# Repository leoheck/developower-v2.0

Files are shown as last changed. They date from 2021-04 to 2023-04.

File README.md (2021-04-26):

## Developower-v2.0

This project is an effort to recreate Developower-v2.0 board on Kicad.

This is the Developower-v2.0 board used on those Chinese 3018 CNC's.

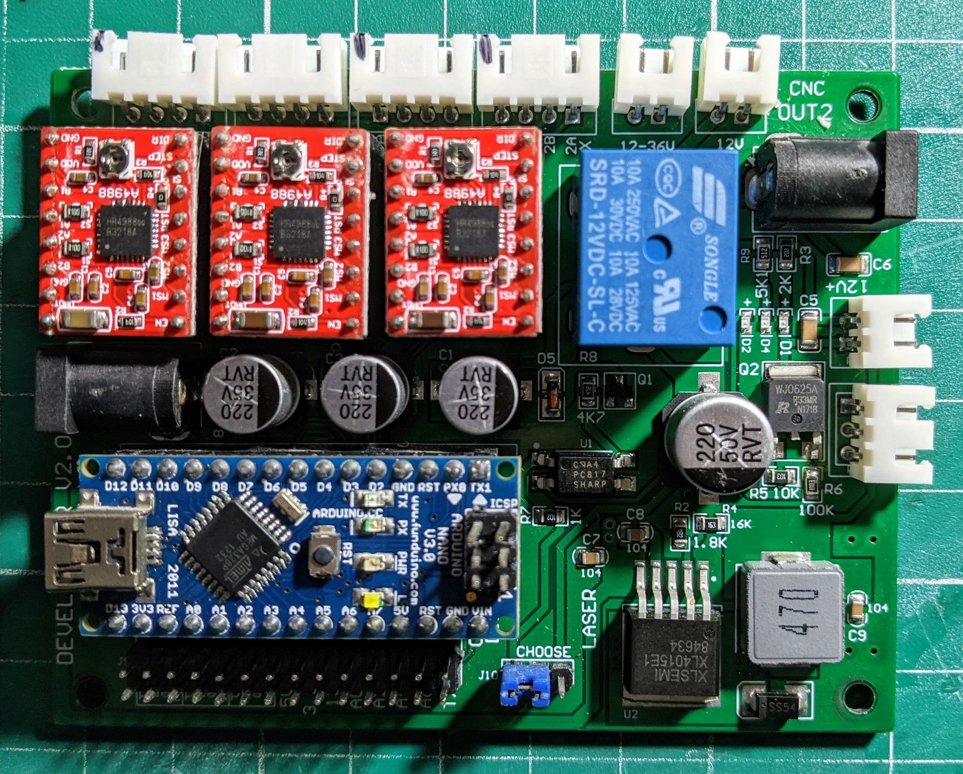
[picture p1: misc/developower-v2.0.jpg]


This is the current version of the layout, but it is still a work in progress.

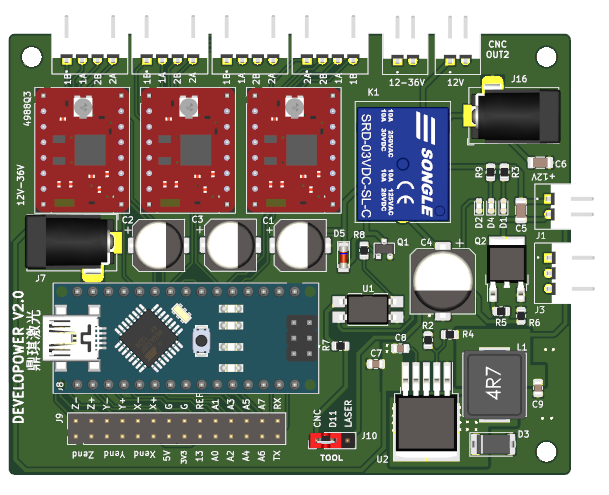
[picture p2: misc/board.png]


A simple cover for the board can be found here too.

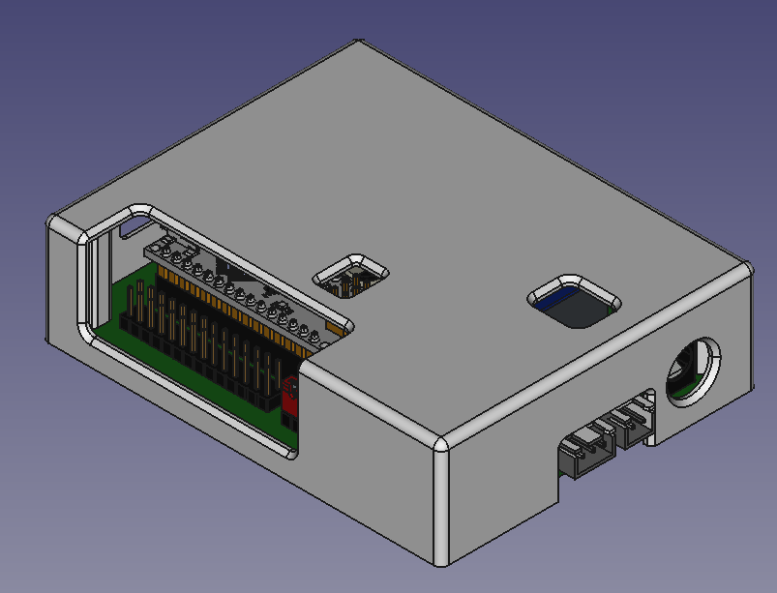
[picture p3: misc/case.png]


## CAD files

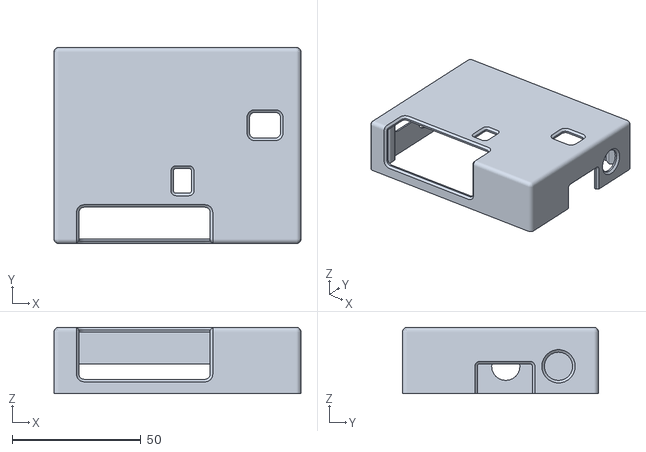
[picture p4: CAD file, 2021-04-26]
case/cover.stl
96.0 x 76.2 x 25.8

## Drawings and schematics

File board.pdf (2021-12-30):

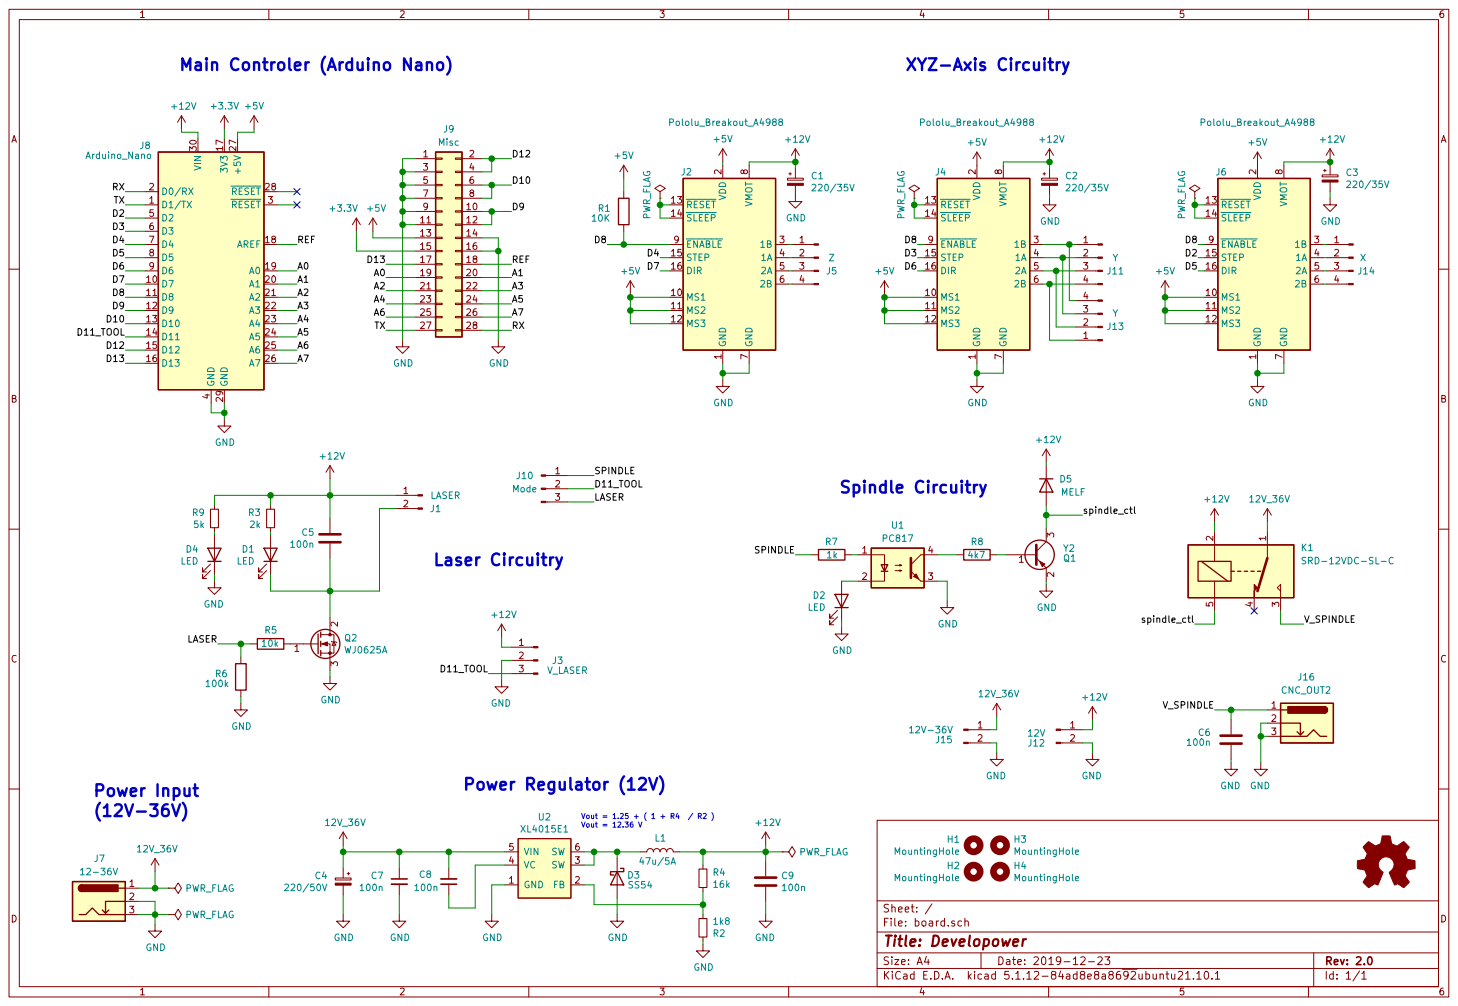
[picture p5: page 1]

9 | 10
11 | 12

1 MS1 10 MS2 11 MS3 12 RESET 13 SLEEP 14 STEP 15 DIR 16 VDD

2 3 Q2WJ0625A GND
Id: 1/1 Title: Developower File: board.sch Sheet: / R5

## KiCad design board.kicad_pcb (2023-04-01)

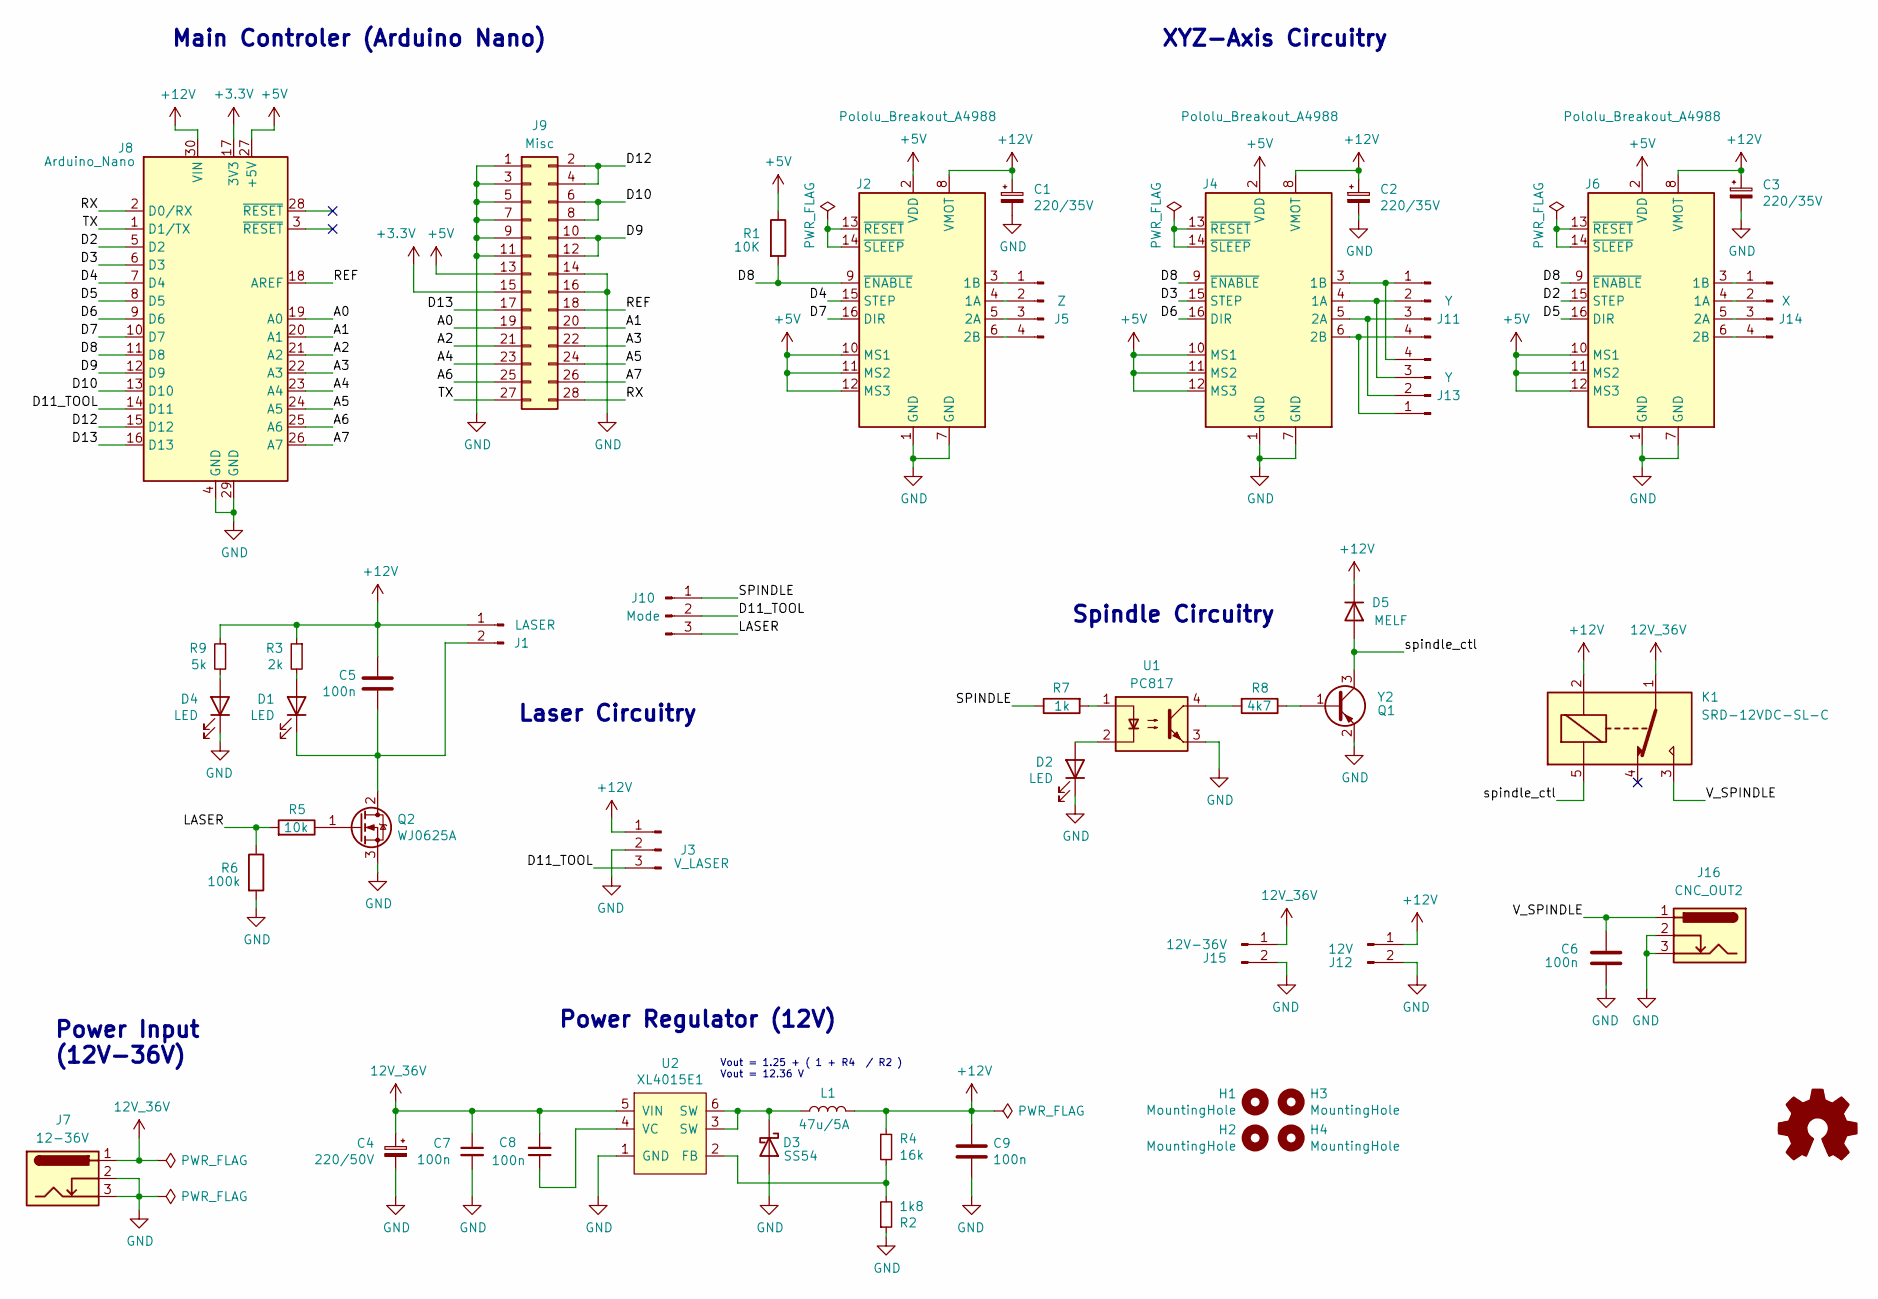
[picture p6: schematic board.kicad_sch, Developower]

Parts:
C1, C2, C3: 220/35V; CP_Elec_8x10
C4: 220/50V; CP_Elec_10x10.5
C5, C6: 100n; C_1206_3216Metric
C7, C8, C9: 100n; C_0805_2012Metric
D1, D2, D4: LED; LED_0603_1608Metric
D3: SS54; D_2512_6332Metric
D5: MELF; D_MiniMELF
H1, H2, H3, H4: MountingHole; MountingHole_3.2mm_M3
J1: LASER; JST_S2B-XH-A(LF)(SN)
J2, J4, J6: Pololu_Breakout_A4988; Pololu_Breakout-16_15.2x20.3mm
J3: V_LASER; JST_S3B-XH-A(LF)(SN)
J5: Z; JST_S4B-XH-A(LF)(SN)
J7: 12-36V; BarrelJack_Horizontal
J8: Arduino_Nano
J9: Misc; PinHeader_2x14_P2.54mm_Vertical
J10: Mode; PinHeader_1x03_P2.54mm_Vertical
J11, J13: Y; JST_S4B-XH-A(LF)(SN)
J12: 12V; JST_S2B-XH-A(LF)(SN)
J14: X; JST_S4B-XH-A(LF)(SN)
J15: 12V-36V; JST_S2B-XH-A(LF)(SN)
J16: CNC_OUT2; BarrelJack_Horizontal
K1: SRD-12VDC-SL-C; Relay_SPDT_SANYOU_SRD_Series_Form_C
L1: 47u/5A; L_Vishay_IHLP-4040
Q1: Y2; SC-59
Q2: WJ0625A; TO-252-2
R1: 10K; R_0805_2012Metric
R2: 1k8; R_0805_2012Metric
R3: 2k; R_0805_2012Metric
R4: 16k; R_0805_2012Metric
R5: 10k; R_0805_2012Metric
R6: 100k; R_0805_2012Metric
R7: 1k; R_0805_2012Metric
R8: 4k7; R_0805_2012Metric
R9: 5k; R_0805_2012Metric
T1: Logo_Open_Hardware_Small; chinese-text
U1: PC817; SMDIP-4_W9.53mm
U2: XL4015E1; TO-263-5_TabPin6

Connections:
12V_36V: C4.1, C7.1, C8.2, J7.1, J15.1, K1.1, U2.5 (VIN)
+3V3: J8.17 (3V3), J9.15
+5V: J2.2 (VDD), J2.10 (MS1), J2.11 (MS2), J2.12 (MS3), J4.2 (VDD), J4.10 (MS1), J4.11 (MS2), J4.12 (MS3), J6.2 (VDD), J6.10 (MS1), J6.11 (MS2), J6.12 (MS3), J8.27 (+5V), J9.13, R1.1
+12V: C1.1, C2.1, C3.1, C5.1, C9.1, D5.1 (K), J1.1, J2.8 (VMOT), J3.1, J4.8 (VMOT), J6.8 (VMOT), J8.30 (VIN), J12.1, K1.2, L1.2, R3.1, R4.1, R9.1
/A0: J8.19 (A0), J9.19
/A1: J8.20 (A1), J9.20
/A2: J8.21 (A2), J9.21
/A3: J8.22 (A3), J9.22
/A4: J8.23 (A4), J9.23
/A5: J8.24 (A5), J9.24
/A6: J8.25 (A6), J9.25
/A7: J8.26 (A7), J9.26
/D2: J6.15 (STEP), J8.5 (D2)
/D3: J4.15 (STEP), J8.6 (D3)
/D4: J2.15 (STEP), J8.7 (D4)
/D5: J6.16 (DIR), J8.8 (D5)
/D6: J4.16 (DIR), J8.9 (D6)
/D7: J2.16 (DIR), J8.10 (D7)
/D8: J2.9 (~ENABLE), J4.9 (~ENABLE), J6.9 (~ENABLE), J8.11 (D8), R1.2
/D9: J8.12 (D9), J9.10, J9.12
/D10: J8.13 (D10), J9.6, J9.8
/D11_TOOL: J3.3, J8.14 (D11), J10.2
/D12: J8.15 (D12), J9.2, J9.4
/D13: J8.16 (D13), J9.17
/LASER: J10.3, R5.2, R6.1
/REF: J8.18 (AREF), J9.18
/RX: J8.2 (D0/RX), J9.28
/SPINDLE: J10.1, R7.1
/TX: J8.1 (D1/TX), J9.27
/V_SPINDLE: C6.2, J16.1, K1.3
/spindle_ctl: D5.2 (A), K1.5, Q1.3 (C)
GND: C1.2, C2.2, C3.2, C4.2, C6.1, C7.2, C9.2, D2.1 (K), D3.2 (A), D4.1 (K), J2.1 (GND), J2.7 (GND), J3.2, J4.1 (GND), J4.7 (GND), J6.1 (GND), J6.7 (GND), J7.2, J7.3, J8.4 (GND), J8.29 (GND), J9.1, J9.3, J9.5, J9.7, J9.9, J9.11, J9.14, J9.16, J12.2, J15.2, J16.2, J16.3, Q1.2 (E), Q2.3 (S), R2.1, R6.2, U1.3, U2.1 (GND)
unnamed: C5.2, D1.1 (K), J1.2, Q2.2 (D)
unnamed: C8.1, U2.4 (VC)
unnamed: D1.2 (A), R3.2
unnamed: D2.2 (A), U1.2
unnamed: D3.1 (K), L1.1, U2.3 (SW), U2.6 (SW)
unnamed: D4.2 (A), R9.2
unnamed: J2.3 (1B), J5.1
unnamed: J2.4 (1A), J5.2
unnamed: J2.5 (2A), J5.3
unnamed: J2.6 (2B), J5.4
unnamed: J2.13 (~RESET), J2.14 (~SLEEP)
unnamed: J4.13 (~RESET), J4.14 (~SLEEP)
unnamed: J6.13 (~RESET), J6.14 (~SLEEP)
unnamed: J4.3 (1B), J11.1, J13.4
unnamed: J4.4 (1A), J11.2, J13.3
unnamed: J4.5 (2A), J11.3, J13.2
unnamed: J4.6 (2B), J11.4, J13.1
unnamed: J6.3 (1B), J14.1
unnamed: J6.4 (1A), J14.2
unnamed: J6.5 (2A), J14.3
unnamed: J6.6 (2B), J14.4
unnamed: Q1.1 (B), R8.1
unnamed: Q2.1 (G), R5.1
unnamed: R2.2, R4.2, U2.2 (FB)
unnamed: R7.2, U1.1
unnamed: R8.2, U1.4

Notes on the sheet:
Laser Circuitry
XYZ-Axis Circuitry
Vout = 1.25 + ( 1 + R4 / R2 ) Vout = 12.36 V
Power Regulator (12V)
Power Input (12V-36V)
Spindle Circuitry
Main Controler (Arduino Nano)

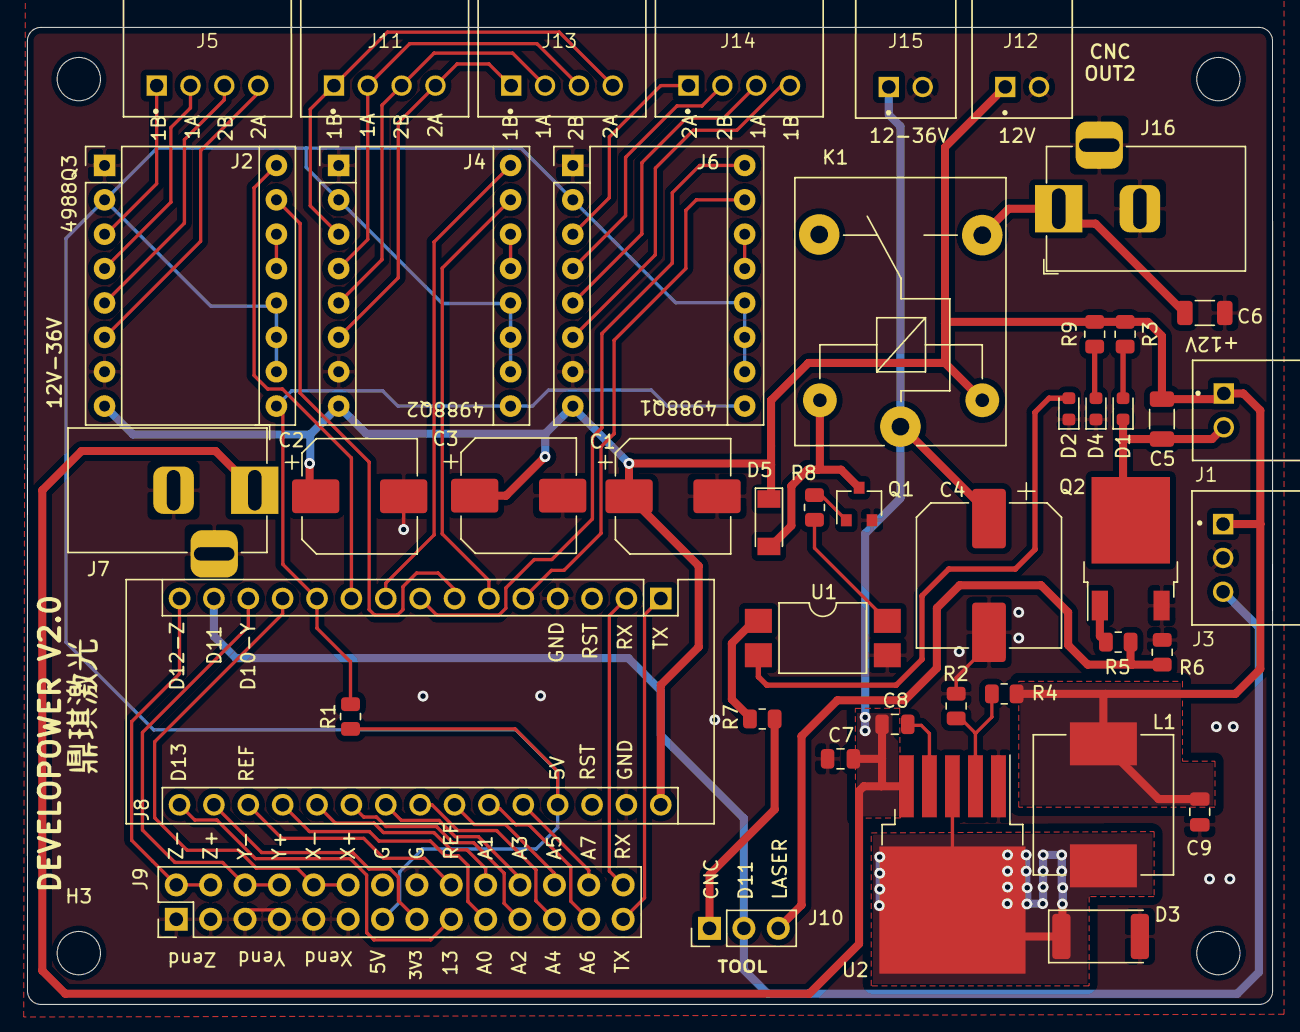
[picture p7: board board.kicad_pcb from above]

Board: 2 copper layers, 92.0 x 72.2 mm, 50 parts (0 on the bottom side), 58 nets.

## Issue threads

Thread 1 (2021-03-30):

Pinout

revenador, 2021-03-30:
Seeing as this seems to be the only repository of knowledge about this board I thought I'd provide the pinout I've probed from my board. Labelled as Developower V2.0. Has a transistor output rather than a relay for the spindle output.

Stepper Drivers
Enable all drivers   D8

X axis
Step  D2
Dir     D5

Y axis
Step  D3
Dir     D6

Z axis
Step  D4
Dir     D7

Spindle/Laser  D11

Limits
Each direction shares a pin for + and -
X+/X-  D9
Y+/Y-  D10
Z+/Z-  D12

Probe is on A5 on my board. Can't remember if that was stock or if I changed it

revenador, 2021-03-30:
It appears this is completely stock for grbl so only useful in that it confirms the board is a stock configuration.

leoheck, 2021-07-13:
Oh, haven't seen this issue before. @revenador this is my work in trying to reverse engineer as much as possible this board. Have you found any issues or you were just sharing your measurements? My works is may not be complete, and my also have issues, so feel free to give your inputs. Thanks.

revenador, 2021-07-13:
Just sharing my measurements. Hopefully it will save someone else some time in future.

leoheck, 2021-07-13:
I see. Cool, thank you.

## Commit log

2019-12-23 Initialize project
    [board.kicad_pcb, board.sch]
2019-12-23 Add board image
2021-04-20 Add more details (extra components, footprints and 3d models)
    [board.kicad_pcb, board.sch]
2021-04-21 Add some interconnections. Fix some missing 3d models.
    [board.kicad_pcb, board.sch]
2021-04-21 Connect extra signals, 90% done
    [board.kicad_pcb, board.sch]
2021-04-22 Add extra power symbol
2021-04-22 Improve connections
    [board.kicad_pcb, board.sch]
2021-04-22 Add 3d printed cover
    [cover.stl]
2021-04-23 Fix description of the power source
2021-04-23 Update some parts
    [board.kicad_pcb, board.sch]
2021-04-23 Fix case
    [cover.stl]
2021-04-24 Add missing connection to the GND
    [board.kicad_pcb, board.sch]
2021-04-24 Fix n-mosfet symbol/footprint and improve circuit
    [board.kicad_pcb, board.sch]
2021-04-24 Update Q1
    [board.kicad_pcb, board.sch]
2021-04-24 Organize schematic sheet
    [board.sch]
2021-04-24 Update board image
2021-04-24 Reduce ERC
    [board.sch]
2021-04-24 Reduce DRC
    [board.kicad_pcb]
2021-04-26 Improve parts placement
    [board.kicad_pcb]
2021-04-26 Organize housing-related files
    [cover.stl]
2021-04-26 Update case
    [cover.stl]
2021-04-26 Power on the Arduino
    [board.kicad_pcb, board.sch]
2021-12-30 Organize schematic a bit
2021-12-30 Update using Kicad 5.1.12
    [board.kicad_pcb, board.sch]
2021-12-30 Convert project to Kicad v6
    [board.kicad_pcb, board.kicad_sch, board.sch]
2023-04-01 Convert to Kicad 7
    [board.kicad_pcb, board.kicad_sch]
